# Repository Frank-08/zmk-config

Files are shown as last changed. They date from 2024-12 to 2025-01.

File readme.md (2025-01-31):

# No Arrows Keyboard

## Change what a key does

1. Open zmk-config/boards/shields/no_arrows/no_arrows.keymap
2. Kayout matches the physical layout
3. Keycodes can be found here: https://zmk.dev/docs/keymaps/list-of-keycodes
4. Commit and Push to repo
5. Firmware wiil be created through github action
6. Once compiled, downlaod firmware.uf2 file
7. Power on Keyboard with boot button pressed
8. Copy firmware.ue2 file to the drive that was mounted
9. keybaord will unmount and boot into new firmware

## STL Generator for case

### Generator is a python script stolen from [jeffminton on github](https://github.com/jeffminton/keyboard_stl_generator)

1. Run `pip install -r requirements.txt`
2. Update parameters.json in zmk-config/case-files/keyboard_stl_generator if neded
3. Run `Python keyboard_stl_generator.py -i zmk-config/dad-no-arrows.json -a -p parameters.json`
4. Files are in zmk-config/dad-no-arrows

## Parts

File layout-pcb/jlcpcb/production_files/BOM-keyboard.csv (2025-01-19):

Comment | Designator | Footprint | LCSC | Quantity
WS2812B | D1,D2 | LED_WS2812B-Mini_PLCC4_3.5x3.5mm | C22371519 | 2
WS2812B | D10,D11,D12,D13,D14,D15,D16,D17,D18,D19,D20,D21,D22,D23,D24,D25,D26,D27,D28,D29,D3,D30,D31,D32,D33,D34,D35,D36,D37,D38,D39,D4,D40,D41,D42,D43,D44,D45,D46,D47,D48,D49,D5,D50,D51,D52,D53,D54,D55,D56,D57,D58,D59,D6,D60,D61,D62,D63,D64,D65,D66,D67,D68,D69,D7,D70,D71,D72,D73,D74,D75,D76,D77,D78,D79,D8,D80,D81,D82,D83,D84,D85,D86,D87,D88,D89,D9,D90,D91,D92,D93,D94 | LED_WS2812B-Mini_PLCC4_3.5x3.5mm | C22464516 | 92
USB_C_Receptacle_USB2.0_16P | J1 | USB_C_Receptacle_G-Switch_GT-USB-7010ASV | C2988369 | 1
D | D_0,D_1,D_10,D_11,D_12,D_13,D_14,D_15,D_16,D_17,D_18,D_19,D_2,D_20,D_21,D_22,D_23,D_24,D_25,D_26,D_27,D_28,D_29,D_3,D_30,D_31,D_32,D_33,D_34,D_35,D_36,D_37,D_38,D_39,D_4,D_40,D_41,D_42,D_43,D_44,D_45,D_46,D_47,D_48,D_49,D_5,D_50,D_51,D_52,D_53,D_54,D_55,D_56,D_57,D_58,D_59,D_6,D_60,D_61,D_62,D_63,D_64,D_65,D_66,D_67,D_68,D_69,D_7,D_70,D_71,D_72,D_73,D_74,D_75,D_76,D_77,D_78,D_79,D_8,D_80,D_81,D_82,D_83,D_84,D_85,D_86,D_87,D_88,D_89,D_9,D_90 | D_SOD-123 | C81598 | 91
KEYSW | K_19 | MXOnly-1U-Hotswap |  | 1
KEYSW | K_20 | MXOnly-1U-Hotswap |  | 1
KEYSW | K_16 | MXOnly-1U-Hotswap |  | 1
KEYSW | K_F11 | MXOnly-1U-Hotswap |  | 1
KEYSW | K_45 | MXOnly-1U-Hotswap |  | 1
KEYSW | K_13 | MXOnly-1U-Hotswap |  | 1
KEYSW | K_75 | MXOnly-1U-Hotswap |  | 1
KEYSW | K_56 | MXOnly-1U-Hotswap |  | 1
KEYSW | K_46 | MXOnly-1U-Hotswap |  | 1
KEYSW | K_78 | MXOnly-1U-Hotswap |  | 1
KEYSW | K_74 | MXOnly-1U-Hotswap |  | 1
KEYSW | K_35 | MXOnly-1U-Hotswap |  | 1
KEYSW | K_15 | MXOnly-1U-Hotswap |  | 1
ESC | K_ESC1 | MXOnly-1U-Hotswap |  | 1
KEYSW | K_38 | MXOnly-1U-Hotswap |  | 1
KEYSW | K_79 | MXOnly-1U-Hotswap |  | 1
KEYSW | K_86 | MXOnly-1.25U-Hotswap |  | 1
KEYSW | K_F9 | MXOnly-1U-Hotswap |  | 1
KEYSW | K_88 | MXOnly-1.25U-Hotswap |  | 1
KEYSW | K_81 | MXOnly-1.25U-Hotswap |  | 1
KEYSW | K_23 | MXOnly-1U-Hotswap |  | 1
KEYSW | K_63 | MXOnly-1U-Hotswap |  | 1
KEYSW | K_67 | MXOnly-1U-Hotswap |  | 1
KEYSW | K_53 | MXOnly-1U-Hotswap |  | 1
KEYSW | K_72 | MXOnly-1U-Hotswap |  | 1
KEYSW | K_47 | MXOnly-1U-Hotswap |  | 1
KEYSW | K_60 | MXOnly-1U-Hotswap |  | 1
KEYSW | K_F7 | MXOnly-1U-Hotswap |  | 1
KEYSW2.25 | K_61 | MXOnly-2.25U-Hotswap |  | 1
KEYSW | K_25 | MXOnly-1U-Hotswap |  | 1
KEYSW | K_F8 | MXOnly-1U-Hotswap |  | 1
KEYSW | K_F12 | MXOnly-1U-Hotswap |  | 1
KEYSW | K_33 | MXOnly-1U-Hotswap |  | 1
KEYSW2.75 | K_76 | MXOnly-2.75U-Hotswap |  | 1
KEYSW | K_73 | MXOnly-1U-Hotswap |  | 1
KEYSW | K_70 | MXOnly-1U-Hotswap |  | 1
KEYSW | K_24 | MXOnly-1U-Hotswap |  | 1
KEYSW | K_54 | MXOnly-1U-Hotswap |  | 1
KEYSW | K_29 | MXOnly-1U-Hotswap |  | 1
KEYSW | K_F10 | MXOnly-1U-Hotswap |  | 1
KEYSW | K_32 | MXOnly-1U-Hotswap |  | 1
KEYSW | K_34 | MXOnly-1U-Hotswap |  | 1
KEYSW | K_68 | MXOnly-1U-Hotswap |  | 1
KEYSW | K_42 | MXOnly-1U-Hotswap |  | 1
KEYSW | K_14 | MXOnly-1U-Hotswap |  | 1
KEYSW6.25 | K_84 | MXOnly-6.25U-Hotswap |  | 1
KEYSW | K_39 | MXOnly-1U-Hotswap |  | 1
KEYSW2 | K_89 | MXOnly-2U-Hotswap |  | 1
KEYSW | K_59 | MXOnly-1U-Hotswap |  | 1
KEYSW | K_62 | MXOnly-1U-Hotswap |  | 1
KEYSW1.75 | K_49 | MXOnly-1.75U-Hotswap |  | 1
KEYSW | K_18 | MXOnly-1U-Hotswap |  | 1
KEYSW | K_17 | MXOnly-1U-Hotswap |  | 1
KEYSW | K_F1 | MXOnly-1U-Hotswap |  | 1
KEYSW | K_87 | MXOnly-1.25U-Hotswap |  | 1
KEYSW | K_85 | MXOnly-1.25U-Hotswap |  | 1
KEYSW | K_83 | MXOnly-1.25U-Hotswap |  | 1
KEYSW | K_77 | MXOnly-1U-Hotswap |  | 1
KEYSW1.5 | K_44 | MXOnly-1.5U-Hotswap |  | 1
KEYSW | K_30 | MXOnly-1U-Hotswap |  | 1
KEYSW | K_66 | MXOnly-1U-Hotswap |  | 1
KEYSW | K_64 | MXOnly-1U-Hotswap |  | 1
KEYSW | K_58 | MXOnly-1U-Hotswap |  | 1
KEYSW | K_21 | MXOnly-1U-Hotswap |  | 1
KEYSW | K_43 | MXOnly-1U-Hotswap |  | 1
KEYSW | K_48 | MXOnly-1U-Hotswap |  | 1
KEYSW | K_71 | MXOnly-1U-Hotswap |  | 1
KEYSW | K_40 | MXOnly-1U-Hotswap |  | 1
KEYSW | K_52 | MXOnly-1U-Hotswap |  | 1
KEYSW | K_80 | MXOnly-1U-Hotswap |  | 1
KEYSW | K_F5 | MXOnly-1U-Hotswap |  | 1
KEYSW | K_F2 | MXOnly-1U-Hotswap |  | 1
KEYSW | K_82 | MXOnly-1.25U-Hotswap |  | 1
KEYSW | K_27 | MXOnly-1U-Hotswap |  | 1
KEYSW | K_90 | MXOnly-1U-Hotswap |  | 1
KEYSW | K_51 | MXOnly-1U-Hotswap |  | 1
KEYSW | K_22 | MXOnly-1U-Hotswap |  | 1
KEYSW2 | K_26 | MXOnly-2U-Hotswap |  | 1
KEYSW | K_69 | MXOnly-1U-Hotswap |  | 1
KEYSW | K_28 | MXOnly-1U-Hotswap |  | 1
KEYSW | K_F4 | MXOnly-1U-Hotswap |  | 1
KEYSW1.5 | K_31 | MXOnly-1.5U-Hotswap |  | 1
KEYSW | K_57 | MXOnly-1U-Hotswap |  | 1
KEYSW | K_50 | MXOnly-1U-Hotswap |  | 1
KEYSW | K_37 | MXOnly-1U-Hotswap |  | 1
KEYSW | K_36 | MXOnly-1U-Hotswap |  | 1
KEYSW | K_F6 | MXOnly-1U-Hotswap |  | 1
KEYSW2.25 | K_65 | MXOnly-2.25U-Hotswap |  | 1
KEYSW | K_41 | MXOnly-1U-Hotswap |  | 1
KEYSW | K_55 | MXOnly-1U-Hotswap |  | 1
KEYSW | K_F3 | MXOnly-1U-Hotswap |  | 1
RP2040_Stamp | U1 | RP2xxx_Stamp_SMD |  | 1
SW_Push | SW1 | SW_PUSH_6mm |  | 1
5K1 | R1 | R_0603_1608Metric_Pad0.98x0.95mm_HandSolder |  | 1
SRV05-4 | U2 | SOT-23-6 |  | 1
5K1 | R2 | R_0603_1608Metric_Pad0.98x0.95mm_HandSolder |  | 1
+5V | TP3 | TestPoint_Pad_D3.0mm |  | 1
GND | TP4 | TestPoint_Pad_D3.0mm |  | 1

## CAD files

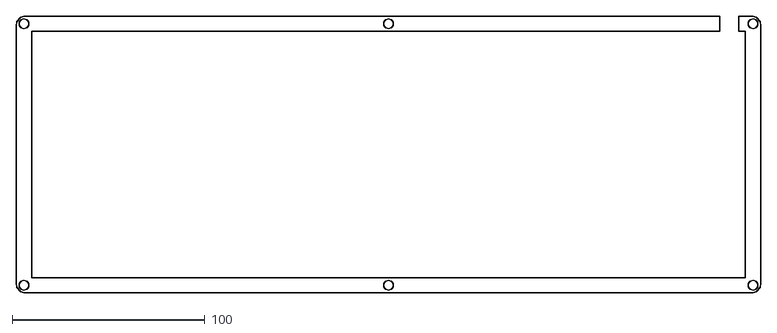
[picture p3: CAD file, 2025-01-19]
case-files/f7311c84de18158c865d323e90fa32f0937720a5_open.dxf
386.7 x 143.8

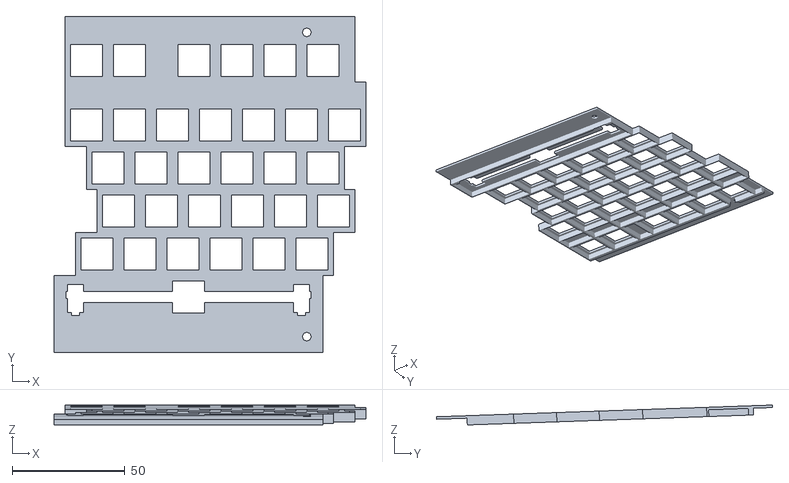
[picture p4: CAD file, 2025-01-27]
dad-no-arrows/stl/dad-no-arrows_section_1_plate.stl
138.1 x 148.8 x 8.83

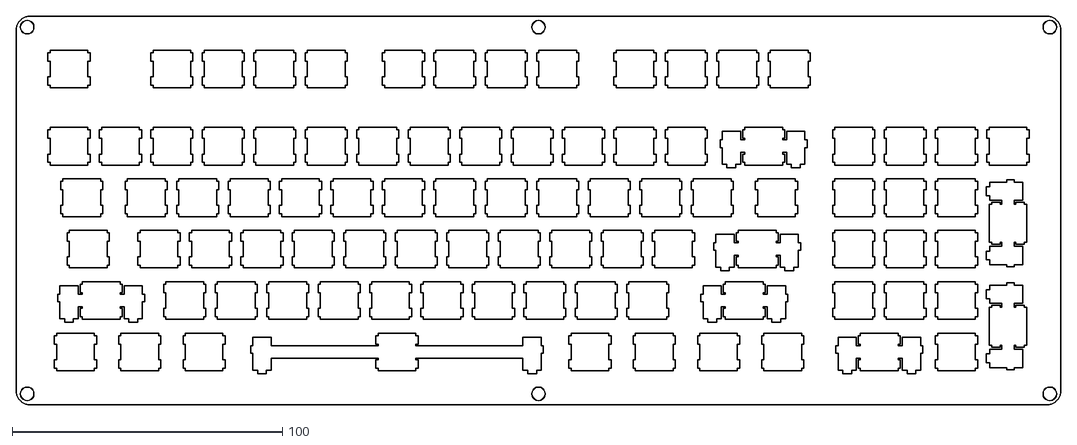
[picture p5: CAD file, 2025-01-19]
case-files/f7311c84de18158c865d323e90fa32f0937720a5_switch.dxf
386.7 x 143.8

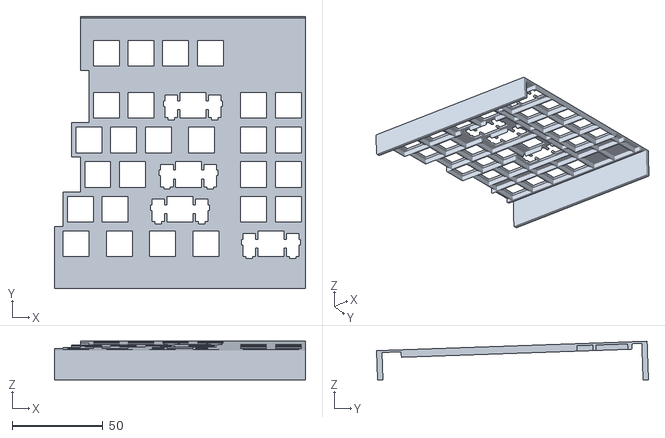
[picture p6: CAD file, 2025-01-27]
dad-no-arrows/stl/dad-no-arrows_section_2_top.stl
138.1 x 149.5 x 21.2

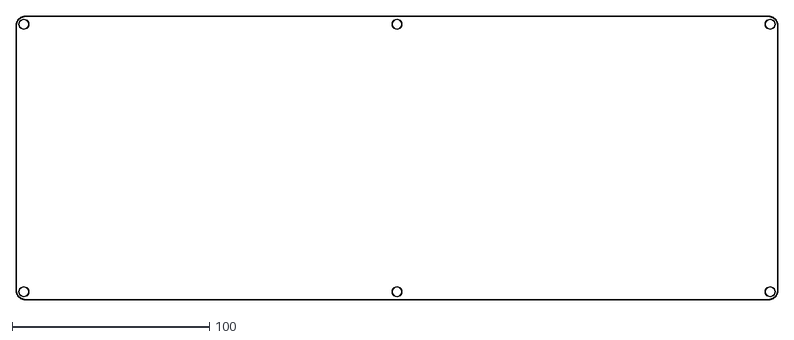
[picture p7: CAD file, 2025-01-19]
case-files/f7311c84de18158c865d323e90fa32f0937720a5_bottom.dxf
386.7 x 143.8

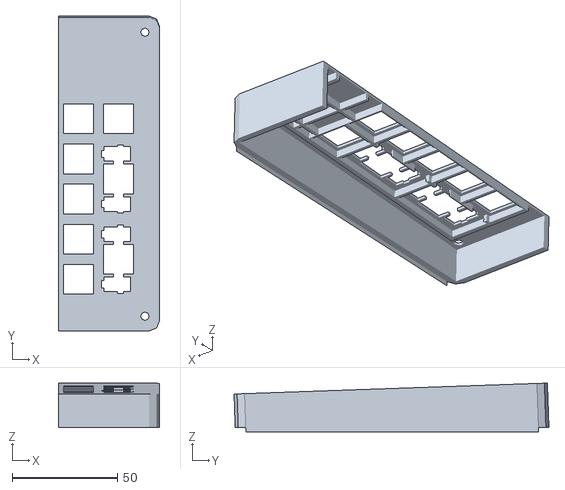
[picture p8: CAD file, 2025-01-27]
dad-no-arrows/stl/dad-no-arrows_section_3_all.stl
48.1 x 149.5 x 23.2

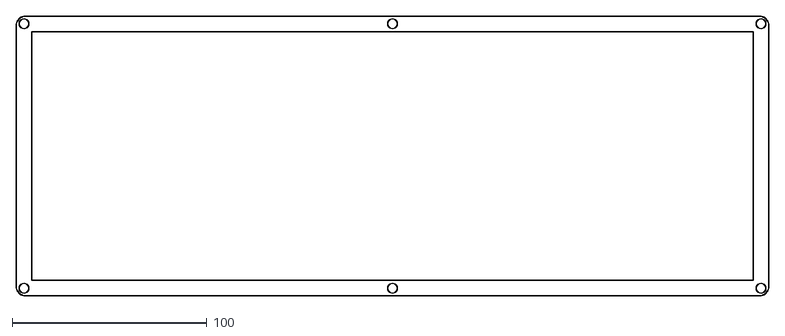
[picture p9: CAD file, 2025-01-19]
case-files/f7311c84de18158c865d323e90fa32f0937720a5_closed.dxf
386.7 x 143.8

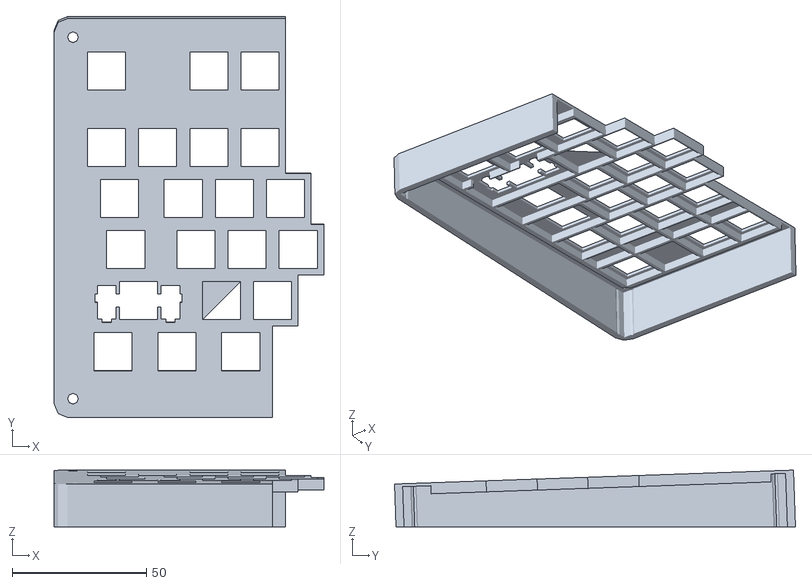
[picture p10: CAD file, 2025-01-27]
dad-no-arrows/stl/dad-no-arrows_section_0_top.stl
100.5 x 149.5 x 21.2

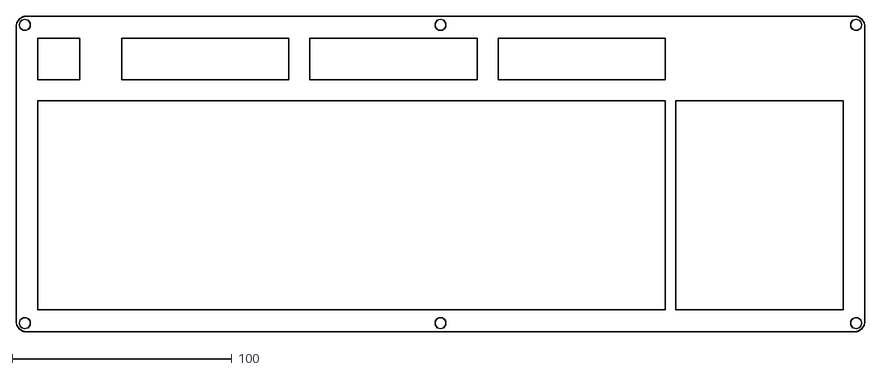
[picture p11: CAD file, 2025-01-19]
case-files/f7311c84de18158c865d323e90fa32f0937720a5_top.dxf
386.7 x 143.8

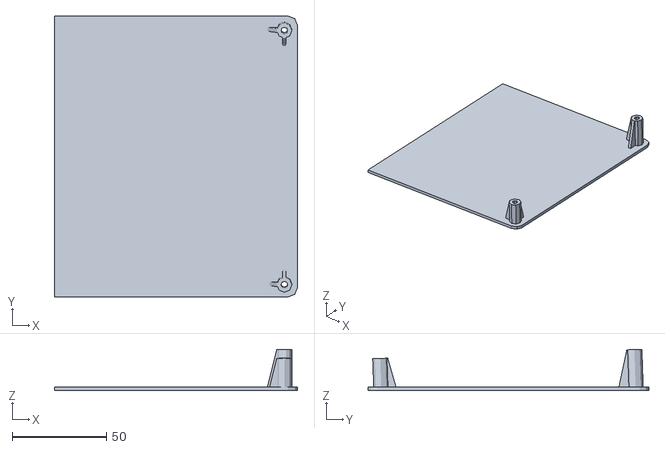
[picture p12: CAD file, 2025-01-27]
dad-no-arrows/stl/dad-no-arrows_section_2_bottom.stl
128.9 x 149.0 x 22.0

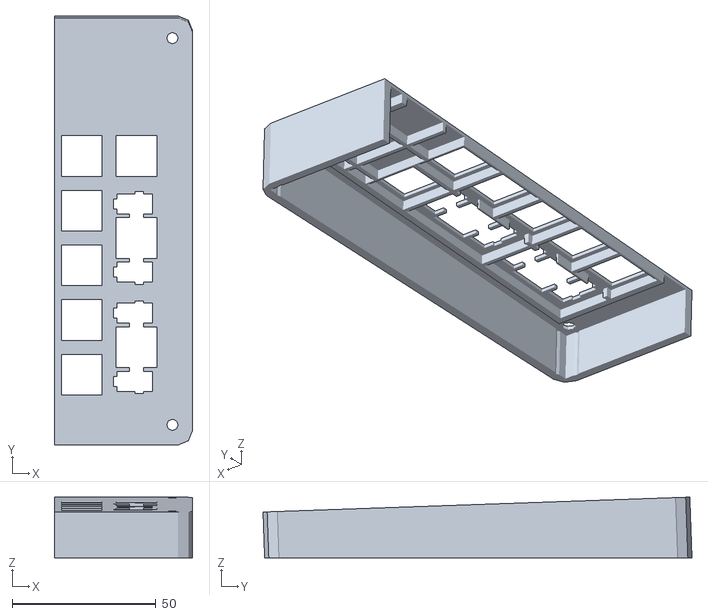
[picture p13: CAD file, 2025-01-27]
dad-no-arrows/stl/dad-no-arrows_section_3_top.stl
48.1 x 149.5 x 21.2

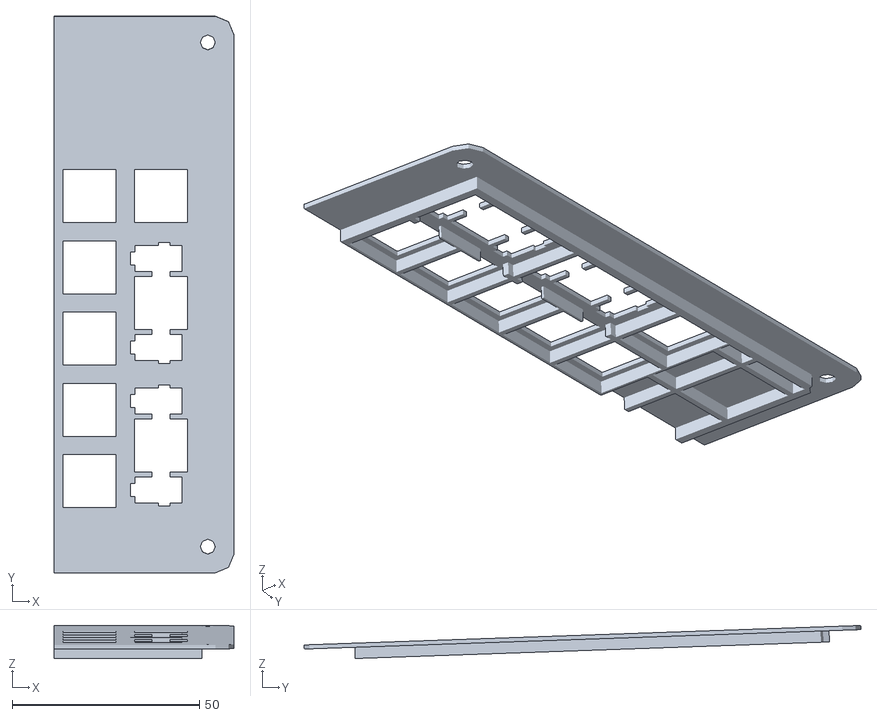
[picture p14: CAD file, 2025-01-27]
dad-no-arrows/stl/dad-no-arrows_section_3_plate.stl
48.1 x 148.8 x 8.83

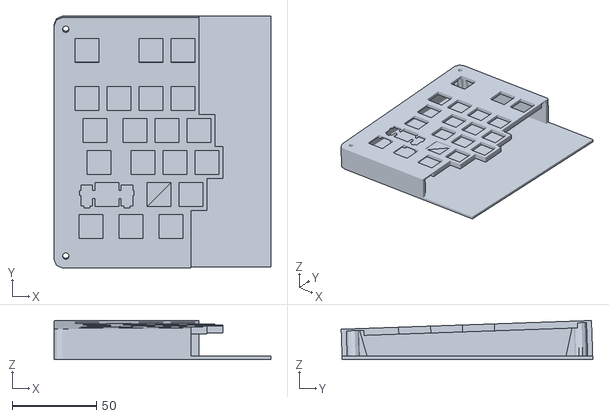
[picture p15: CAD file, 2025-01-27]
dad-no-arrows/stl/dad-no-arrows_section_0_all.stl
128.9 x 149.5 x 23.2

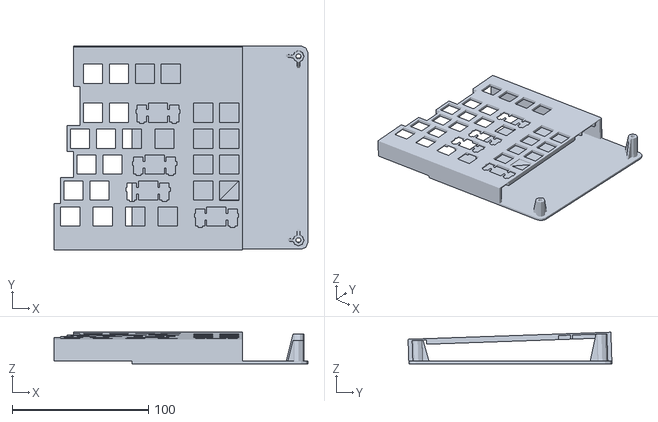
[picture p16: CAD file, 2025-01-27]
dad-no-arrows/stl/dad-no-arrows_section_2_all.stl
186.2 x 149.5 x 23.2

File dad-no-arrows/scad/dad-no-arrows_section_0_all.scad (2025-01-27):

// Generated by SolidPython 1.1.3 on 2025-01-26 22:52:06
$fn = 8;


union() {
	difference() {
		rotate(a = 2, v = [1, 0, 0]) {
			difference() {
				union() {
					translate(v = [0, 0, 15.4445000000]) {
						translate(v = [0, 138.8250000000, 0]) {
							translate(v = [10, 0, 0]) {
								difference() {
									union() {
										difference() {
											union() {
												union() {
													translate(v = [183.3562500000, 0, 0]) {
														translate(v = [0, -64.4125000000, 0]) {
															minkowski() {
																cube(center = true, size = [376.7125000000, 138.8250000000, 0.5555000000]);
																cylinder(center = true, h = 0.5555000000, r = 5);
															}
														}
													}
													translate(v = [0, -123.8250000000, 0]) {
														translate(v = [0, 0, -3.5555000000]) {
															difference() {
																translate(v = [-1.5000000000, 0, 0]) {
																	translate(v = [0, -1.5000000000, 0]) {
																		cube(size = [369.7125000000, 126.8250000000, 4.1110000000]);
																	}
																}
																cube(size = [366.7125000000, 123.8250000000, 3.0000000000]);
															}
														}
													}
													translate(v = [0.0000000000, 0, 0]) {
														translate(v = [0, 0.0000000000, 0]) {
															union() {
																translate(v = [9.5250000000, 0, 0]) {
																	translate(v = [0, -9.5250000000, 0]) {
																		cube(center = true, size = [19.0500000000, 19.0500000000, 1.1110000000]);
																	}
																}
																translate(v = [9.5250000000, 0, 0]) {
																	translate(v = [0, -9.5250000000, 0]) {
																		difference() {
																			translate(v = [0, 0, -1.5000000000]) {
																				cube(center = true, size = [19.0500000000, 19.0500000000, 4.1110000000]);
																			}
																			translate(v = [0, 0, -1.5000000000]) {
																				cube(center = true, size = [17.5500000000, 17.5500000000, 6.0000000000]);
																			}
																		}
																	}
																}
															}
														}
													}
													translate(v = [0.0000000000, 0, 0]) {
														translate(v = [0, -19.0500000000, 0]) {
															union() {
																translate(v = [9.5250000000, 0, 0]) {
																	translate(v = [0, -9.5250000000, 0]) {
																		cube(center = true, size = [19.0500000000, 19.0500000000, 1.1110000000]);
																	}
																}
																translate(v = [9.5250000000, 0, 0]) {
																	translate(v = [0, -9.5250000000, 0]) {
																		difference() {
																			translate(v = [0, 0, -1.5000000000]) {
																				cube(center = true, size = [19.0500000000, 19.0500000000, 4.1110000000]);
																			}
																			translate(v = [0, 0, -1.5000000000]) {
																				cube(center = true, size = [17.5500000000, 17.5500000000, 6.0000000000]);
																			}
																		}
																	}
																}
															}
														}
													}
													translate(v = [0.0000000000, 0, 0]) {
														translate(v = [0, -38.1000000000, 0]) {
															union() {
																translate(v = [9.5250000000, 0, 0]) {
																	translate(v = [0, -9.5250000000, 0]) {
																		cube(center = true, size = [19.0500000000, 19.0500000000, 1.1110000000]);
																	}
																}
																translate(v = [9.5250000000, 0, 0]) {
																	translate(v = [0, -9.5250000000, 0]) {
																		difference() {
																			translate(v = [0, 0, -1.5000000000]) {
																				cube(center = true, size = [19.0500000000, 19.0500000000, 4.1110000000]);
																			}
																			translate(v = [0, 0, -1.5000000000]) {
																				cube(center = true, size = [17.5500000000, 17.5500000000, 6.0000000000]);
																			}
																		}
																	}
																}
															}
														}
													}
													translate(v = [0.0000000000, 0, 0]) {
														translate(v = [0, -57.1500000000, 0]) {
															union() {
																translate(v = [9.5250000000, 0, 0]) {
																	translate(v = [0, -9.5250000000, 0]) {
																		cube(center = true, size = [19.0500000000, 19.0500000000, 1.1110000000]);
																	}
																}
																translate(v = [9.5250000000, 0, 0]) {
																	translate(v = [0, -9.5250000000, 0]) {
																		difference() {
																			translate(v = [0, 0, -1.5000000000]) {
																				cube(center = true, size = [19.0500000000, 19.0500000000, 4.1110000000]);
																			}
																			translate(v = [0, 0, -1.5000000000]) {
																				cube(center = true, size = [17.5500000000, 17.5500000000, 6.0000000000]);
																			}
																		}
																	}
																}
															}
														}
													}
													translate(v = [0.0000000000, 0, 0]) {
														translate(v = [0, -76.2000000000, 0]) {
															union() {
																translate(v = [9.5250000000, 0, 0]) {
																	translate(v = [0, -9.5250000000, 0]) {
																		cube(center = true, size = [19.0500000000, 19.0500000000, 1.1110000000]);
																	}
																}
																translate(v = [9.5250000000, 0, 0]) {
																	translate(v = [0, -9.5250000000, 0]) {
																		difference() {
																			translate(v = [0, 0, -1.5000000000]) {
																				cube(center = true, size = [19.0500000000, 19.0500000000, 4.1110000000]);
																			}
																			translate(v = [0, 0, -1.5000000000]) {
																				cube(center = true, size = [17.5500000000, 17.5500000000, 6.0000000000]);
																			}
																		}
																	}
																}
															}
														}
													}
													translate(v = [0.0000000000, 0, 0]) {
														translate(v = [0, -95.2500000000, 0]) {
															union() {
																translate(v = [9.5250000000, 0, 0]) {
																	translate(v = [0, -9.5250000000, 0]) {
																		cube(center = true, size = [19.0500000000, 19.0500000000, 1.1110000000]);
																	}
																}
																translate(v = [9.5250000000, 0, 0]) {
																	translate(v = [0, -9.5250000000, 0]) {
																		difference() {
																			translate(v = [0, 0, -1.5000000000]) {
																				cube(center = true, size = [19.0500000000, 19.0500000000, 4.1110000000]);
																			}
																			translate(v = [0, 0, -1.5000000000]) {
																				cube(center = true, size = [17.5500000000, 17.5500000000, 6.0000000000]);
																			}
																		}
																	}
																}
															}
														}
													}
													translate(v = [0.0000000000, 0, 0]) {
														translate(v = [0, -114.3000000000, 0]) {
															union() {
																translate(v = [9.5250000000, 0, 0]) {
																	translate(v = [0, -4.7625000000, 0]) {
																		cube(center = true, size = [19.0500000000, 9.5250000000, 1.1110000000]);
																	}
																}
																translate(v = [9.5250000000, 0, 0]) {
																	translate(v = [0, -4.7625000000, 0]) {
																		difference() {
																			translate(v = [0, 0, -1.5000000000]) {
																				cube(center = true, size = [19.0500000000, 9.5250000000, 4.1110000000]);
																			}
																			translate(v = [0, 0, -1.5000000000]) {
																				cube(center = true, size = [17.5500000000, 8.0250000000, 6.0000000000]);
																			}
																		}
																	}
																}
															}
														}
													}
													translate(v = [19.0500000000, 0, 0]) {
														translate(v = [0, 0.0000000000, 0]) {
															union() {
																translate(v = [9.5250000000, 0, 0]) {
																	translate(v = [0, -9.5250000000, 0]) {
																		cube(center = true, size = [19.0500000000, 19.0500000000, 1.1110000000]);
																	}
																}
																translate(v = [9.5250000000, 0, 0]) {
																	translate(v = [0, -9.5250000000, 0]) {
																		difference() {
																			translate(v = [0, 0, -1.5000000000]) {
																				cube(center = true, size = [19.0500000000, 19.0500000000, 4.1110000000]);
																			}
																			translate(v = [0, 0, -1.5000000000]) {
																				cube(center = true, size = [17.5500000000, 17.5500000000, 6.0000000000]);
																			}
																		}
																	}
																}
															}
														}
													}
													translate(v = [19.0500000000, 0, 0]) {
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

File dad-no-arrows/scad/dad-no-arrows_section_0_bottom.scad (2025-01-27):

// Generated by SolidPython 1.1.3 on 2025-01-26 22:52:06
$fn = 8;


difference() {
	intersection() {
		union() {
			difference() {
				rotate(a = 2, v = [1, 0, 0]) {
					translate(v = [0, 0, 15.4445000000]) {
						translate(v = [0, 138.8250000000, 0]) {
							translate(v = [10, 0, 0]) {
								difference() {
									translate(v = [-3, 0, 0]) {
										translate(v = [0, -131.8250000000, 0]) {
											translate(v = [0, 0, -68.5555000000]) {
												union() {
													translate(v = [0, 0, 0]) {
														translate(v = [0, 0, 0]) {
															union() {
																cylinder(h = 68, r = 4.0000000000);
																rotate(a = 90, v = [1, 0, 0]) {
																	linear_extrude(center = true, height = 2) {
																		polygon(paths = [[0, 1, 2, 3]], points = [[0, 0], [0, 68], [4.0000000000, 68], [21.0000000000, 0]]);
																	}
																}
																rotate(a = 90, v = [0, 0, 1]) {
																	rotate(a = 90, v = [1, 0, 0]) {
																		linear_extrude(center = true, height = 2) {
																			polygon(paths = [[0, 1, 2, 3]], points = [[0, 0], [0, 68], [4.0000000000, 68], [21.0000000000, 0]]);
																		}
																	}
																}
															}
														}
													}
													translate(v = [0, 0, 0]) {
														translate(v = [0, 134.8250000000, 0]) {
															union() {
																cylinder(h = 68, r = 4.0000000000);
																rotate(a = 90, v = [1, 0, 0]) {
																	linear_extrude(center = true, height = 2) {
																		polygon(paths = [[0, 1, 2, 3]], points = [[0, 0], [0, 68], [4.0000000000, 68], [21.0000000000, 0]]);
																	}
																}
																rotate(a = 270, v = [0, 0, 1]) {
																	rotate(a = 90, v = [1, 0, 0]) {
																		linear_extrude(center = true, height = 2) {
																			polygon(paths = [[0, 1, 2, 3]], points = [[0, 0], [0, 68], [4.0000000000, 68], [21.0000000000, 0]]);
																		}
																	}
																}
															}
														}
													}
													translate(v = [372.7125000000, 0, 0]) {
														translate(v = [0, 134.8250000000, 0]) {
															union() {
																cylinder(h = 68, r = 4.0000000000);
																rotate(a = 180, v = [0, 0, 1]) {
																	rotate(a = 90, v = [1, 0, 0]) {
																		linear_extrude(center = true, height = 2) {
																			polygon(paths = [[0, 1, 2, 3]], points = [[0, 0], [0, 68], [4.0000000000, 68], [21.0000000000, 0]]);
																		}
																	}
																}
																rotate(a = 270, v = [0, 0, 1]) {
																	rotate(a = 90, v = [1, 0, 0]) {
																		linear_extrude(center = true, height = 2) {
																			polygon(paths = [[0, 1, 2, 3]], points = [[0, 0], [0, 68], [4.0000000000, 68], [21.0000000000, 0]]);
																		}
																	}
																}
															}
														}
													}
													translate(v = [372.7125000000, 0, 0]) {
														translate(v = [0, 0, 0]) {
															union() {
																cylinder(h = 68, r = 4.0000000000);
																rotate(a = 180, v = [0, 0, 1]) {
																	rotate(a = 90, v = [1, 0, 0]) {
																		linear_extrude(center = true, height = 2) {
																			polygon(paths = [[0, 1, 2, 3]], points = [[0, 0], [0, 68], [4.0000000000, 68], [21.0000000000, 0]]);
																		}
																	}
																}
																rotate(a = 90, v = [0, 0, 1]) {
																	rotate(a = 90, v = [1, 0, 0]) {
																		linear_extrude(center = true, height = 2) {
																			polygon(paths = [[0, 1, 2, 3]], points = [[0, 0], [0, 68], [4.0000000000, 68], [21.0000000000, 0]]);
																		}
																	}
																}
															}
														}
													}
													translate(v = [186.3562500000, 0, 0]) {
														translate(v = [0, 134.8250000000, 0]) {
															union() {
																cylinder(h = 68, r = 4.0000000000);
																rotate(a = 90, v = [1, 0, 0]) {
																	linear_extrude(center = true, height = 2) {
																		polygon(paths = [[0, 1, 2, 3]], points = [[0, 0], [0, 68], [4.0000000000, 68], [21.0000000000, 0]]);
																	}
																}
																rotate(a = 180, v = [0, 0, 1]) {
																	rotate(a = 90, v = [1, 0, 0]) {
																		linear_extrude(center = true, height = 2) {
																			polygon(paths = [[0, 1, 2, 3]], points = [[0, 0], [0, 68], [4.0000000000, 68], [21.0000000000, 0]]);
																		}
																	}
																}
															}
														}
													}
													translate(v = [186.3562500000, 0, 0]) {
														translate(v = [0, 0, 0]) {
															union() {
																cylinder(h = 68, r = 4.0000000000);
																rotate(a = 90, v = [1, 0, 0]) {
																	linear_extrude(center = true, height = 2) {
																		polygon(paths = [[0, 1, 2, 3]], points = [[0, 0], [0, 68], [4.0000000000, 68], [21.0000000000, 0]]);
																	}
																}
																rotate(a = 180, v = [0, 0, 1]) {
																	rotate(a = 90, v = [1, 0, 0]) {
																		linear_extrude(center = true, height = 2) {
																			polygon(paths = [[0, 1, 2, 3]], points = [[0, 0], [0, 68], [4.0000000000, 68], [21.0000000000, 0]]);
																		}
																	}
																}
															}
														}
													}
												}
											}
										}
									}
									translate(v = [-3, 0, 0]) {
										translate(v = [0, -131.8250000000, 0]) {
											union() {
												translate(v = [0, 0, 0]) {
													translate(v = [0, 0, 0]) {
														cylinder(center = true, h = 272, r = 1.8250000000);
													}
												}
												translate(v = [0, 0, 0]) {
													translate(v = [0, 134.8250000000, 0]) {
														cylinder(center = true, h = 272, r = 1.8250000000);
													}
												}
												translate(v = [372.7125000000, 0, 0]) {
													translate(v = [0, 134.8250000000, 0]) {
														cylinder(center = true, h = 272, r = 1.8250000000);
													}
												}
												translate(v = [372.7125000000, 0, 0]) {
													translate(v = [0, 0, 0]) {
														cylinder(center = true, h = 272, r = 1.8250000000);
													}
												}
												translate(v = [186.3562500000, 0, 0]) {
													translate(v = [0, 134.8250000000, 0]) {
														cylinder(center = true, h = 272, r = 1.8250000000);
													}
												}
												translate(v = [186.3562500000, 0, 0]) {
													translate(v = [0, 0, 0]) {
														cylinder(center = true, h = 272, r = 1.8250000000);
													}
												}
											}
										}
									}
								}
							}
						}
					}
				}
				translate(v = [0, 0, -2]) {
					translate(v = [0, 0, -100]) {
						translate(v = [0, -74.4125000000, 0]) {
							translate(v = [-193.3562500000, 0, 0]) {
								cube(size = [773.4250000000, 297.6500000000, 100]);
							}
						}
					}
				}
			}
			intersection() {
				translate(v = [0, 0, -2]) {
					translate(v = [-193.3562500000, 0, 0]) {
						translate(v = [0, -74.4125000000, 0]) {
							cube(size = [773.4250000000, 297.6500000000, 2]);
						}
					}
				}
				rotate(a = 2, v = [1, 0, 0]) {
					translate(v = [0, 0, 15.4445000000]) {
						translate(v = [0, 138.8250000000, 0]) {
							translate(v = [10, 0, 0]) {
								translate(v = [0, 0, -34.0000000000]) {
									translate(v = [183.3562500000, 0, 0]) {
										translate(v = [0, -64.4125000000, 0]) {
											minkowski() {
												cube(center = true, size = [376.7125000000, 138.8250000000, 68]);
												cylinder(center = true, h = 0.5555000000, r = 5);
											}
										}
									}
								}
							}
						}
					}
				}
			}
		}
		translate(v = [0, 0, 15.4445000000]) {
			translate(v = [0, 138.8250000000, 0]) {
				translate(v = [10, 0, 0]) {
					translate(v = [-10.0000000000, 0, 0]) {
						translate(v = [0, -223.2375000000, 0]) {
							translate(v = [0, 0, -34.0000000000]) {
								cube(size = [128.9041666667, 297.6500000000, 136]);
							}
						}
					}
				}
			}
		}
	}
	rotate(a = 2, v = [1, 0, 0]) {
		translate(v = [0, 0, 15.4445000000]) {
			translate(v = [0, 138.8250000000, 0]) {
				translate(v = [10, 0, 0]) {
					translate(v = [-3, 0, 0]) {
						translate(v = [0, -131.8250000000, 0]) {
							union() {
								translate(v = [0, 0, 0]) {
									translate(v = [0, 0, 0]) {
										cylinder(center = true, h = 272, r = 1.8250000000);
									}
								}
								translate(v = [0, 0, 0]) {
									translate(v = [0, 134.8250000000, 0]) {
										cylinder(center = true, h = 272, r = 1.8250000000);
									}
								}
								translate(v = [372.7125000000, 0, 0]) {
									translate(v = [0, 134.8250000000, 0]) {
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

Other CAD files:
dad-no-arrows/stl/dad-no-arrows_section_0_bottom.stl
dad-no-arrows/stl/dad-no-arrows_section_1_bottom.stl
dad-no-arrows/stl/dad-no-arrows_section_1_top.stl
dad-no-arrows/stl/dad-no-arrows_section_2_plate.stl
dad-no-arrows/scad/dad-no-arrows_section_0_plate.scad
dad-no-arrows/scad/dad-no-arrows_section_0_top.scad
dad-no-arrows/scad/dad-no-arrows_section_1_all.scad
dad-no-arrows/scad/dad-no-arrows_section_1_bottom.scad
dad-no-arrows/scad/dad-no-arrows_section_1_plate.scad
dad-no-arrows/scad/dad-no-arrows_section_1_top.scad
dad-no-arrows/scad/dad-no-arrows_section_2_all.scad
dad-no-arrows/scad/dad-no-arrows_section_2_bottom.scad
dad-no-arrows/scad/dad-no-arrows_section_2_plate.scad
dad-no-arrows/scad/dad-no-arrows_section_2_top.scad
dad-no-arrows/scad/dad-no-arrows_section_3_all.scad
dad-no-arrows/scad/dad-no-arrows_section_3_plate.scad
dad-no-arrows/scad/dad-no-arrows_section_3_top.scad
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

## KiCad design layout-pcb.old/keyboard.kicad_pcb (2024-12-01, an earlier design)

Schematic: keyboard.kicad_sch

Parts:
D1, D2, D3, D4, D5, D6, D7, D8, D9, D10, D11, D12, D13, D14, D15, D16, D17, D18, D19, D20, D21, D22, D23, D24, D25, D26, D27, D28, D29, D30, D31, D32, D33, D34, D35, D36, D37, D38, D39, D40, D41, D42, D43, D44, D45, D46, D47, D48, D49, D50, D51, D52, D53, D54, D55, D56, D57, D58, D59, D60, D61, D62, D63, D64, D65, D66, D67, D68, D69, D70, D71, D72, D73, D74, D75, D76, D77, D78, D79, D80, D81, D82, D83, D84, D85, D86, D87, D88, D89, D90, D91, D92, D93, D94: WS2812B; LED_WS2812B-Mini_PLCC4_3.5x3.5mm; Mouser 485-4684
D_0, D_1, D_2, D_3, D_4, D_5, D_6, D_7, D_8, D_9, D_10, D_11, D_12, D_13, D_14, D_15, D_16, D_17, D_18, D_19, D_20, D_21, D_22, D_23, D_24, D_25, D_26, D_27, D_28, D_29, D_30, D_31, D_32, D_33, D_34, D_35, D_36, D_37, D_38, D_39, D_40, D_41, D_42, D_43, D_44, D_45, D_46, D_47, D_48, D_49, D_50, D_51, D_52, D_53, D_54, D_55, D_56, D_57, D_58, D_59, D_60, D_61, D_62, D_63, D_64, D_65, D_66, D_67, D_68, D_69, D_70, D_71, D_72, D_73, D_74, D_75, D_76, D_77, D_78, D_79, D_80, D_81, D_82, D_83, D_84, D_85, D_86, D_87, D_88, D_89, D_90: D; D_SOD-123; Mouser 485-5099
J1: USB_C_Receptacle_USB2.0_16P; USB_C_Receptacle_G-Switch_GT-USB-7010ASV; Mouser 179-UJ20CHGSMTP16TR
JP2: SolderJumper_2_Open; SolderJumper-2_P1.3mm_Open_Pad1.0x1.5mm
K_13, K_14, K_15, K_16, K_17, K_18, K_19, K_20, K_21, K_22, K_23, K_24, K_25, K_27, K_28, K_29, K_30, K_32, K_33, K_34, K_35, K_36, K_37, K_38, K_39, K_40, K_41, K_42, K_43, K_45, K_46, K_47, K_48, K_50, K_51, K_52, K_53, K_54, K_55, K_56, K_57, K_58, K_59, K_60, K_62, K_63, K_64, K_66, K_67, K_68, K_69, K_70, K_71, K_72, K_73, K_74, K_75, K_77, K_78, K_79, K_80, K_90: KEYSW; MXOnly-1U-Hotswap; Mouser 540-MX1A-E1NN
K_26, K_89: KEYSW2; MXOnly-2U-Hotswap; Mouser 540-MX1A-E1NN
K_31, K_44: KEYSW1.5; MXOnly-1.5U-Hotswap; Mouser 540-MX1A-E1NN
K_49: KEYSW1.75; MXOnly-1.75U-Hotswap; Mouser 540-MX1A-E1NN
K_61, K_65: KEYSW2.25; MXOnly-2.25U-Hotswap; Mouser 540-MX1A-E1NN
K_76: KEYSW2.75; MXOnly-2.75U-Hotswap; Mouser 540-MX1A-E1NN
K_81, K_82, K_83, K_85, K_86, K_87, K_88: KEYSW; MXOnly-1.25U-Hotswap; Mouser 540-MX1A-E1NN
K_84: KEYSW6.25; MXOnly-6.25U-Hotswap; Mouser 540-MX1A-E1NN
K_ESC1: ESC; MXOnly-1U-Hotswap; Mouser 540-MX1A-E1NN
K_F1, K_F2, K_F3, K_F4, K_F5, K_F6, K_F7, K_F8, K_F9, K_F10, K_F11, K_F12: KEYSW; MXOnly-1U-Hotswap; Mouser 540-MX1A-E1NN
R1, R2: 5K1; R_0603_1608Metric_Pad0.98x0.95mm_HandSolder; Mouser 791-RMC1/32-5101FPA
SW1: SW_Push; SW_PUSH_6mm
TP1: LED_PWR; TestPoint_Pad_D3.0mm
TP2: LED_GND; TestPoint_Pad_D3.0mm
TP3: +5V; TestPoint_Pad_D3.0mm
TP4: GND; TestPoint_Pad_D3.0mm
U1: RP2040_Stamp; RP2xxx_Stamp_SMD
U2: SRV05-4; SOT-23-6

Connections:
14p2-32p4: D14.2 (DOUT), D32.4 (DIN)
26p4-27p2: D26.4 (DIN), D27.2 (DOUT)
31p4 - 13p2: D13.2 (DOUT), D31.4 (DIN)
39p2-40p4: D39.2 (DOUT), D40.4 (DIN)
49p2-65p4: D49.2 (DOUT), D65.4 (DIN)
50p2-66p4: D50.2 (DOUT), D66.4 (DIN)
53p2-52p4: D52.4 (DIN), D53.2 (DOUT)
78p2-79p4: D78.2 (DOUT), D79.4 (DIN)
81p2-91p4: D81.2 (DOUT), D91.4 (DIN)
GND: J1.A1 (GND), J1.A12 (GND), J1.B1 (GND), J1.B12 (GND), SW1.1, TP4.1, U1.31 (GND), U2.2 (VN)
LED-Status IN: D92.4 (DIN), U1.4 (GPIO3)
LED_DTA_IN: D1.4 (DIN), U1.3 (GPIO2)
LED_DTA_OUT: JP2.2 (B)
LED_GND: D1.3 (VSS), D2.3 (VSS), D3.3 (VSS), D4.3 (VSS), D5.3 (VSS), D6.3 (VSS), D7.3 (VSS), D8.3 (VSS), D9.3 (VSS), D10.3 (VSS), D11.3 (VSS), D12.3 (VSS), D13.3 (VSS), D14.3 (VSS), D15.3 (VSS), D16.3 (VSS), D17.3 (VSS), D18.3 (VSS), D19.3 (VSS), D20.3 (VSS), D21.3 (VSS), D22.3 (VSS), D23.3 (VSS), D24.3 (VSS), D25.3 (VSS), D26.3 (VSS), D27.3 (VSS), D28.3 (VSS), D29.3 (VSS), D30.3 (VSS), D31.3 (VSS), D32.3 (VSS), D33.3 (VSS), D34.3 (VSS), D35.3 (VSS), D36.3 (VSS), D37.3 (VSS), D38.3 (VSS), D39.3 (VSS), D40.3 (VSS), D41.3 (VSS), D42.3 (VSS), D43.3 (VSS), D44.3 (VSS), D45.3 (VSS), D46.3 (VSS), D47.3 (VSS), D48.3 (VSS), D49.3 (VSS), D50.3 (VSS), D51.3 (VSS), D52.3 (VSS), D53.3 (VSS), D54.3 (VSS), D55.3 (VSS), D56.3 (VSS), D57.3 (VSS), D58.3 (VSS), D59.3 (VSS), D60.3 (VSS), D61.3 (VSS), D62.3 (VSS), D63.3 (VSS), D64.3 (VSS), D65.3 (VSS), D66.3 (VSS), D67.3 (VSS), D68.3 (VSS), D69.3 (VSS), D70.3 (VSS), D71.3 (VSS), D72.3 (VSS), D73.3 (VSS), D74.3 (VSS), D75.3 (VSS), D76.3 (VSS), D77.3 (VSS), D78.3 (VSS), D79.3 (VSS), D80.3 (VSS), D81.3 (VSS), D82.3 (VSS), D83.3 (VSS), D84.3 (VSS), D85.3 (VSS), D86.3 (VSS), D87.3 (VSS), D88.3 (VSS), D89.3 (VSS), D90.3 (VSS), D91.3 (VSS), D92.3 (VSS), D93.3 (VSS), D94.3 (VSS)
unnamed: D1.2 (DOUT), D2.4 (DIN)
unnamed: D2.2 (DOUT), D3.4 (DIN)
unnamed: D3.2 (DOUT), D4.4 (DIN)
unnamed: D4.2 (DOUT), D5.4 (DIN)
unnamed: D5.2 (DOUT), D6.4 (DIN)
unnamed: D6.2 (DOUT), D7.4 (DIN)
unnamed: D7.2 (DOUT), D8.4 (DIN)
unnamed: D8.2 (DOUT), D9.4 (DIN)
unnamed: D9.2 (DOUT), D10.4 (DIN)
unnamed: D10.2 (DOUT), D11.4 (DIN)
unnamed: D11.2 (DOUT), D12.4 (DIN)
unnamed: D12.2 (DOUT), D13.4 (DIN)
unnamed: D14.4 (DIN), D15.2 (DOUT)
unnamed: D15.4 (DIN), D16.2 (DOUT)
unnamed: D16.4 (DIN), D17.2 (DOUT)
unnamed: D17.4 (DIN), D18.2 (DOUT)
unnamed: D18.4 (DIN), D19.2 (DOUT)
unnamed: D19.4 (DIN), D20.2 (DOUT)
unnamed: D20.4 (DIN), D21.2 (DOUT)
unnamed: D21.4 (DIN), D22.2 (DOUT)
unnamed: D22.4 (DIN), D23.2 (DOUT)
unnamed: D23.4 (DIN), D24.2 (DOUT)
unnamed: D24.4 (DIN), D25.2 (DOUT)
unnamed: D25.4 (DIN), D26.2 (DOUT)
unnamed: D27.4 (DIN), D28.2 (DOUT)
unnamed: D28.4 (DIN), D29.2 (DOUT)
unnamed: D29.4 (DIN), D30.2 (DOUT)
unnamed: D30.4 (DIN), D31.2 (DOUT)
unnamed: D32.2 (DOUT), D33.4 (DIN)
unnamed: D33.2 (DOUT), D34.4 (DIN)
unnamed: D34.2 (DOUT), D35.4 (DIN)
unnamed: D35.2 (DOUT), D36.4 (DIN)
unnamed: D36.2 (DOUT), D37.4 (DIN)
unnamed: D37.2 (DOUT), D38.4 (DIN)
unnamed: D38.2 (DOUT), D39.4 (DIN)
unnamed: D40.2 (DOUT), D41.4 (DIN)
unnamed: D41.2 (DOUT), D42.4 (DIN)
unnamed: D42.2 (DOUT), D43.4 (DIN)
unnamed: D43.2 (DOUT), D44.4 (DIN)
unnamed: D44.2 (DOUT), D45.4 (DIN)
unnamed: D45.2 (DOUT), D46.4 (DIN)
unnamed: D46.2 (DOUT), D47.4 (DIN)
unnamed: D47.2 (DOUT), D48.4 (DIN)
unnamed: D48.2 (DOUT), D49.4 (DIN)
unnamed: D50.4 (DIN), D51.2 (DOUT)
unnamed: D51.4 (DIN), D52.2 (DOUT)
unnamed: D53.4 (DIN), D54.2 (DOUT)
unnamed: D54.4 (DIN), D55.2 (DOUT)
unnamed: D55.4 (DIN), D56.2 (DOUT)
unnamed: D56.4 (DIN), D57.2 (DOUT)
unnamed: D57.4 (DIN), D58.2 (DOUT)
unnamed: D58.4 (DIN), D59.2 (DOUT)
unnamed: D59.4 (DIN), D60.2 (DOUT)
unnamed: D60.4 (DIN), D61.2 (DOUT)
unnamed: D61.4 (DIN), D62.2 (DOUT)
unnamed: D62.4 (DIN), D63.2 (DOUT)
unnamed: D63.4 (DIN), D64.2 (DOUT)
unnamed: D64.4 (DIN), D65.2 (DOUT)
unnamed: D66.2 (DOUT), D67.4 (DIN)
unnamed: D67.2 (DOUT), D68.4 (DIN)
unnamed: D68.2 (DOUT), D69.4 (DIN)
unnamed: D69.2 (DOUT), D70.4 (DIN)
unnamed: D70.2 (DOUT), D71.4 (DIN)
unnamed: D71.2 (DOUT), D72.4 (DIN)
unnamed: D72.2 (DOUT), D73.4 (DIN)
unnamed: D73.2 (DOUT), D74.4 (DIN)
unnamed: D74.2 (DOUT), D75.4 (DIN)
unnamed: D75.2 (DOUT), D76.4 (DIN)
unnamed: D76.2 (DOUT), D77.4 (DIN)
unnamed: D77.2 (DOUT), D78.4 (DIN)
unnamed: D79.2 (DOUT), D80.4 (DIN)
unnamed: D80.2 (DOUT), D81.4 (DIN)
unnamed: D82.4 (DIN), D83.2 (DOUT)
unnamed: D83.4 (DIN), D84.2 (DOUT)
unnamed: D84.4 (DIN), D85.2 (DOUT)
unnamed: D85.4 (DIN), D86.2 (DOUT)
unnamed: D86.4 (DIN), D87.2 (DOUT)
unnamed: D87.4 (DIN), D88.2 (DOUT)
unnamed: D88.4 (DIN), D89.2 (DOUT)
unnamed: D89.4 (DIN), D90.2 (DOUT)
unnamed: D90.4 (DIN), D91.2 (DOUT)
unnamed: D92.2 (DOUT), D93.4 (DIN)
unnamed: D93.2 (DOUT), D94.4 (DIN)
unnamed: D_0.2 (A), K_ESC1.2 (ROW)
unnamed: D_1.2 (A), K_F1.2 (ROW)
unnamed: D_2.2 (A), K_F2.2 (ROW)
unnamed: D_3.2 (A), K_F3.2 (ROW)
unnamed: D_4.2 (A), K_F4.2 (ROW)
unnamed: D_5.2 (A), K_F5.2 (ROW)
unnamed: D_6.2 (A), K_F6.2 (ROW)
unnamed: D_7.2 (A), K_F7.2 (ROW)
unnamed: D_8.2 (A), K_F8.2 (ROW)
unnamed: D_9.2 (A), K_F9.2 (ROW)
unnamed: D_10.2 (A), K_F10.2 (ROW)
unnamed: D_11.2 (A), K_F11.2 (ROW)
unnamed: D_12.2 (A), K_F12.2 (ROW)
unnamed: D_13.2 (A), K_13.2 (ROW)
unnamed: D_14.2 (A), K_14.2 (ROW)
unnamed: D_15.2 (A), K_15.2 (ROW)
unnamed: D_16.2 (A), K_16.2 (ROW)
unnamed: D_17.2 (A), K_17.2 (ROW)
unnamed: D_18.2 (A), K_18.2 (ROW)
unnamed: D_19.2 (A), K_19.2 (ROW)
unnamed: D_20.2 (A), K_20.2 (ROW)
unnamed: D_21.2 (A), K_21.2 (ROW)
unnamed: D_22.2 (A), K_22.2 (ROW)
unnamed: D_23.2 (A), K_23.2 (ROW)
unnamed: D_24.2 (A), K_24.2 (ROW)
unnamed: D_25.2 (A), K_25.2 (ROW)
unnamed: D_26.2 (A), K_26.2 (ROW)
unnamed: D_27.2 (A), K_27.2 (ROW)
unnamed: D_28.2 (A), K_28.2 (ROW)
unnamed: D_29.2 (A), K_29.2 (ROW)
unnamed: D_30.2 (A), K_30.2 (ROW)
unnamed: D_31.2 (A), K_31.2 (ROW)
unnamed: D_32.2 (A), K_32.2 (ROW)
unnamed: D_33.2 (A), K_33.2 (ROW)
unnamed: D_34.2 (A), K_34.2 (ROW)
unnamed: D_35.2 (A), K_35.2 (ROW)
unnamed: D_36.2 (A), K_36.2 (ROW)
unnamed: D_37.2 (A), K_37.2 (ROW)
unnamed: D_38.2 (A), K_38.2 (ROW)
unnamed: D_39.2 (A), K_39.2 (ROW)
unnamed: D_40.2 (A), K_40.2 (ROW)
unnamed: D_41.2 (A), K_41.2 (ROW)
unnamed: D_42.2 (A), K_42.2 (ROW)
unnamed: D_43.2 (A), K_43.2 (ROW)
unnamed: D_44.2 (A), K_44.2 (ROW)
unnamed: D_45.2 (A), K_45.2 (ROW)
unnamed: D_46.2 (A), K_46.2 (ROW)
unnamed: D_47.2 (A), K_47.2 (ROW)
unnamed: D_48.2 (A), K_48.2 (ROW)
unnamed: D_49.2 (A), K_49.2 (ROW)
unnamed: D_50.2 (A), K_50.2 (ROW)
unnamed: D_51.2 (A), K_51.2 (ROW)
unnamed: D_52.2 (A), K_52.2 (ROW)
unnamed: D_53.2 (A), K_53.2 (ROW)
unnamed: D_54.2 (A), K_54.2 (ROW)
unnamed: D_55.2 (A), K_55.2 (ROW)
unnamed: D_56.2 (A), K_56.2 (ROW)
unnamed: D_57.2 (A), K_57.2 (ROW)
unnamed: D_58.2 (A), K_58.2 (ROW)
unnamed: D_59.2 (A), K_59.2 (ROW)
unnamed: D_60.2 (A), K_60.2 (ROW)
unnamed: D_61.2 (A), K_61.2 (ROW)
unnamed: D_62.2 (A), K_62.2 (ROW)
unnamed: D_63.2 (A), K_63.2 (ROW)
unnamed: D_64.2 (A), K_64.2 (ROW)
unnamed: D_65.2 (A), K_65.2 (ROW)
unnamed: D_66.2 (A), K_66.2 (ROW)
unnamed: D_67.2 (A), K_67.2 (ROW)
unnamed: D_68.2 (A), K_68.2 (ROW)
unnamed: D_69.2 (A), K_69.2 (ROW)
unnamed: D_70.2 (A), K_70.2 (ROW)
unnamed: D_71.2 (A), K_71.2 (ROW)
unnamed: D_72.2 (A), K_72.2 (ROW)
unnamed: D_73.2 (A), K_73.2 (ROW)
unnamed: D_74.2 (A), K_74.2 (ROW)
unnamed: D_75.2 (A), K_75.2 (ROW)
unnamed: D_76.2 (A), K_76.2 (ROW)
unnamed: D_77.2 (A), K_77.2 (ROW)
unnamed: D_78.2 (A), K_78.2 (ROW)
unnamed: D_79.2 (A), K_79.2 (ROW)
unnamed: D_80.2 (A), K_80.2 (ROW)
unnamed: D_81.2 (A), K_81.2 (ROW)
unnamed: D_82.2 (A), K_82.2 (ROW)
unnamed: D_83.2 (A), K_83.2 (ROW)
unnamed: D_84.2 (A), K_84.2 (ROW)
unnamed: D_85.2 (A), K_85.2 (ROW)
unnamed: D_86.2 (A), K_86.2 (ROW)
unnamed: D_87.2 (A), K_87.2 (ROW)
unnamed: D_88.2 (A), K_88.2 (ROW)
unnamed: D_89.2 (A), K_89.2 (ROW)
unnamed: D_90.2 (A), K_90.2 (ROW)
unnamed: J1.A5 (CC1), R1.1
unnamed: J1.B5 (CC2), R2.1
unnamed: SW1.2, U1.40 (BOOTSEL)
unnamed: J1.A6 (D+), J1.B6 (D+), U1.36 (USB_D+), U2.1 (IO1)
unnamed: J1.A7 (D-), J1.B7 (D-), U1.35 (USB_D-), U2.4 (IO3)
col0: K_13.1 (COL), K_31.1 (COL), K_49.1 (COL), K_65.1 (COL), K_81.1 (COL), K_ESC1.1 (COL), U1.30 (GPIO29)
col1: K_14.1 (COL), K_82.1 (COL), U1.29 (GPIO28)
col2: K_15.1 (COL), K_32.1 (COL), K_50.1 (COL), K_66.1 (COL), K_F1.1 (COL), U1.28 (GPIO27)
col3: K_16.1 (COL), K_33.1 (COL), K_51.1 (COL), K_67.1 (COL), K_83.1 (COL), K_F2.1 (COL), U1.27 (GPIO26)
col4: K_17.1 (COL), K_34.1 (COL), K_52.1 (COL), K_68.1 (COL), K_F3.1 (COL), U1.26 (GPIO25)
col5: K_18.1 (COL), K_35.1 (COL), K_53.1 (COL), K_69.1 (COL), K_F4.1 (COL), U1.25 (GPIO24)
col6: K_19.1 (COL), K_36.1 (COL), K_54.1 (COL), K_70.1 (COL), K_84.1 (COL), U1.24 (GPIO23)
col7: K_20.1 (COL), K_37.1 (COL), K_55.1 (COL), K_71.1 (COL), K_F5.1 (COL), U1.23 (GPIO22)
col8: K_21.1 (COL), K_38.1 (COL), K_56.1 (COL), K_72.1 (COL), K_F6.1 (COL), U1.22 (GPIO21)
col9: K_22.1 (COL), K_39.1 (COL), K_57.1 (COL), K_73.1 (COL), K_F7.1 (COL), U1.21 (GPIO20)
col10: K_23.1 (COL), K_40.1 (COL), K_58.1 (COL), K_74.1 (COL), K_85.1 (COL), K_F8.1 (COL), U1.19 (GPIO18)
col11: K_24.1 (COL), K_41.1 (COL), K_59.1 (COL), K_75.1 (COL), K_86.1 (COL), K_F9.1 (COL), U1.18 (GPIO17)
col12: K_25.1 (COL), K_42.1 (COL), K_60.1 (COL), K_F10.1 (COL), U1.17 (GPIO16)
col13: K_43.1 (COL), K_61.1 (COL), K_76.1 (COL), K_87.1 (COL), K_F11.1 (COL), U1.16 (GPIO15)
col14: K_26.1 (COL), K_44.1 (COL), K_88.1 (COL), K_F12.1 (COL), U1.15 (GPIO14)
col15: K_27.1 (COL), K_45.1 (COL), K_62.1 (COL), K_77.1 (COL), U1.14 (GPIO13)
col16: K_28.1 (COL), K_46.1 (COL), K_63.1 (COL), K_78.1 (COL), K_89.1 (COL), U1.13 (GPIO12)
col17: K_29.1 (COL), K_47.1 (COL), K_64.1 (COL), K_79.1 (COL), K_90.1 (COL), U1.12 (GPIO11)
col18: K_30.1 (COL), K_48.1 (COL), K_80.1 (COL), U1.11 (GPIO10)
row0: D_0.1 (K), D_1.1 (K), D_2.1 (K), D_3.1 (K), D_4.1 (K), D_5.1 (K), D_6.1 (K), D_7.1 (K), D_8.1 (K), D_9.1 (K), D_10.1 (K), D_11.1 (K), D_12.1 (K), U1.10 (GPIO9)
row1: D_13.1 (K), D_14.1 (K), D_15.1 (K), D_16.1 (K), D_17.1 (K), D_18.1 (K), D_19.1 (K), D_20.1 (K), D_21.1 (K), D_22.1 (K), D_23.1 (K), D_24.1 (K), D_25.1 (K), D_26.1 (K), D_27.1 (K), D_28.1 (K), D_29.1 (K), D_30.1 (K), U1.9 (GPIO8)
row2: D_31.1 (K), D_32.1 (K), D_33.1 (K), D_34.1 (K), D_35.1 (K), D_36.1 (K), D_37.1 (K), D_38.1 (K), D_39.1 (K), D_40.1 (K), D_41.1 (K), D_42.1 (K), D_43.1 (K), D_44.1 (K), D_45.1 (K), D_46.1 (K), D_47.1 (K), D_48.1 (K), U1.8 (GPIO7)
row3: D_49.1 (K), D_50.1 (K), D_51.1 (K), D_52.1 (K), D_53.1 (K), D_54.1 (K), D_55.1 (K), D_56.1 (K), D_57.1 (K), D_58.1 (K), D_59.1 (K), D_60.1 (K), D_61.1 (K), D_62.1 (K), D_63.1 (K), D_64.1 (K), U1.7 (GPIO6)
row4: D_65.1 (K), D_66.1 (K), D_67.1 (K), D_68.1 (K), D_69.1 (K), D_70.1 (K), D_71.1 (K), D_72.1 (K), D_73.1 (K), D_74.1 (K), D_75.1 (K), D_76.1 (K), D_77.1 (K), D_78.1 (K), D_79.1 (K), D_80.1 (K), U1.6 (GPIO5)
row5: D_81.1 (K), D_82.1 (K), D_83.1 (K), D_84.1 (K), D_85.1 (K), D_86.1 (K), D_87.1 (K), D_88.1 (K), D_89.1 (K), D_90.1 (K), U1.5 (GPIO4)

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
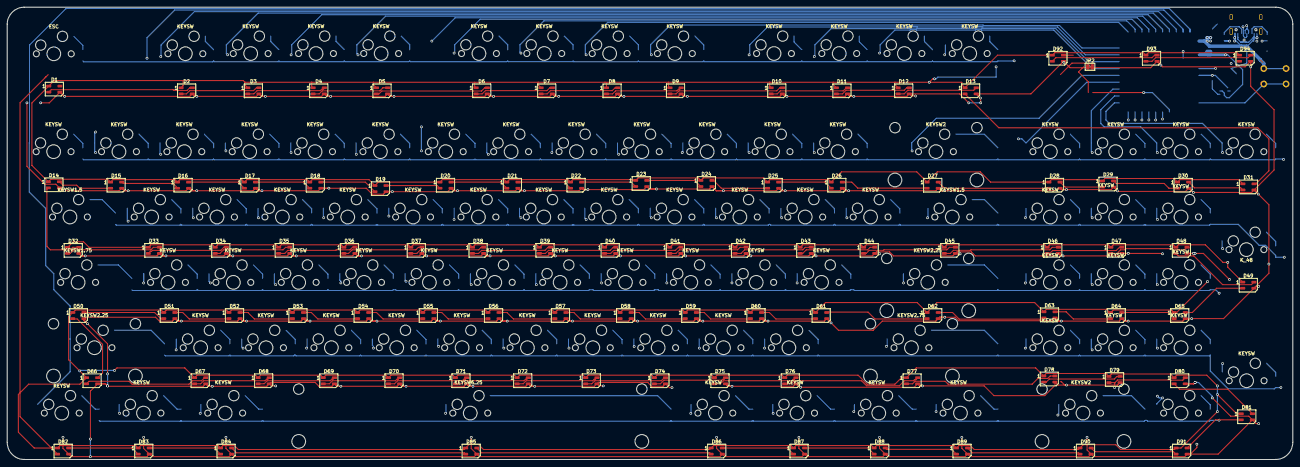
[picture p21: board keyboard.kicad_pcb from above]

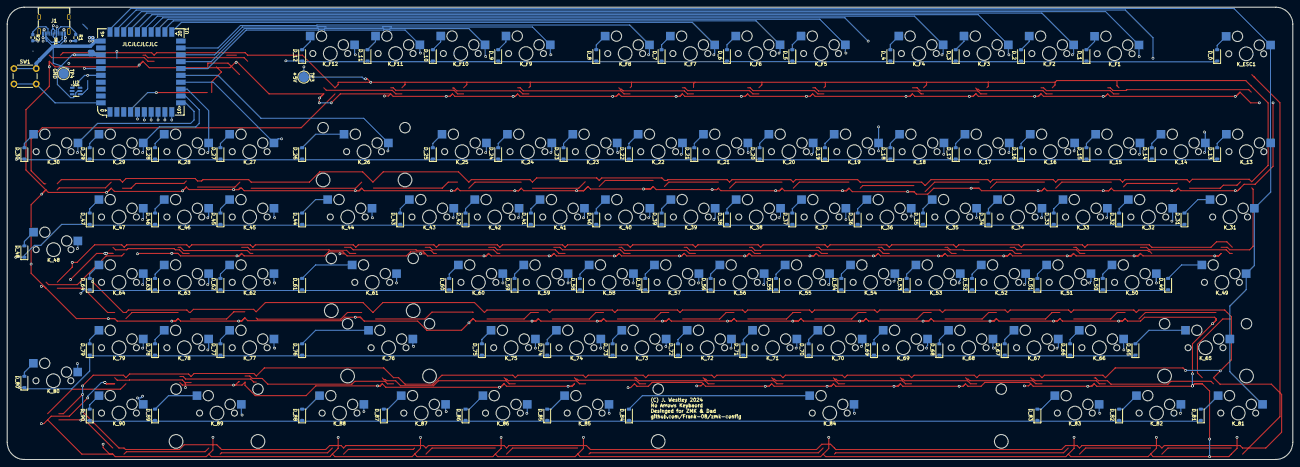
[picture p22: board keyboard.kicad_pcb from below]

Board: 4 copper layers, 374.7 x 131.8 mm, 285 parts (99 on the bottom side), 217 nets.

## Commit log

2024-10-28 pcb files
    [keyboard-B_Cu.gbr, keyboard-B_Mask.gbr, keyboard-B_Paste.gbr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]
2024-11-03 pcb basic wiring
    [keyboard.kicad_pcb, keyboard.kicad_sch]
2024-11-08 LED placemnet #D hotswap and switch
    [keyboard.kicad_pcb, keyboard.kicad_sch]
2024-11-10 LED Pwr + Gnd moved to top LED planes removed
    [BOM-keyboard.csv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]
2024-11-10 Add JLCx3
    [keyboard.kicad_pcb]
2024-11-10 Add Gerber
    [CPL-keyboard.csv, keyboard-CuBottom.gbr, keyboard-CuIn1.gbr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]
2024-11-11 PCB Update
    [keyboard.kicad_sch]
2024-11-11 pcb
    pcb
2024-11-16 gen updates /w Dad
    [keyboard.kicad_pcb, keyboard.kicad_sch]
2024-12-01 Update PCB with PJW
    [keyboard.kicad_pcb, keyboard.kicad_sch]
2025-01-19 STL gen and svg and dxf files + updates
    [BOM-keyboard.csv, dad-no-arrows_section_0_all.scad, dad-no-arrows_section_0_all.stl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]
2025-01-22 Moved CCS 1 and CC2 to GND
    [dad-no-arrows_section_0_all.scad, dad-no-arrows_section_0_all.stl, dad-no-arrows_section_0_bottom.scad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]
2025-01-27 c
    i
    Please enter the commit message for your changes. Lines starting
    [dad-no-arrows_section_0_all.scad, dad-no-arrows_section_0_all.stl, dad-no-arrows_section_0_bottom.scad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]
2025-02-05 Increased case top margin to 15
